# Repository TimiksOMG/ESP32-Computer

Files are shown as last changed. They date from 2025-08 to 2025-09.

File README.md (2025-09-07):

<h1>About</h1>
This is an open source computer with a custom language called TimCode and a DOS-like operating system called HamburgerOS<br>

It uses the <b>esp32-s3</b> chip with the <b>ILI9341</b> tft screen as a display.<br>
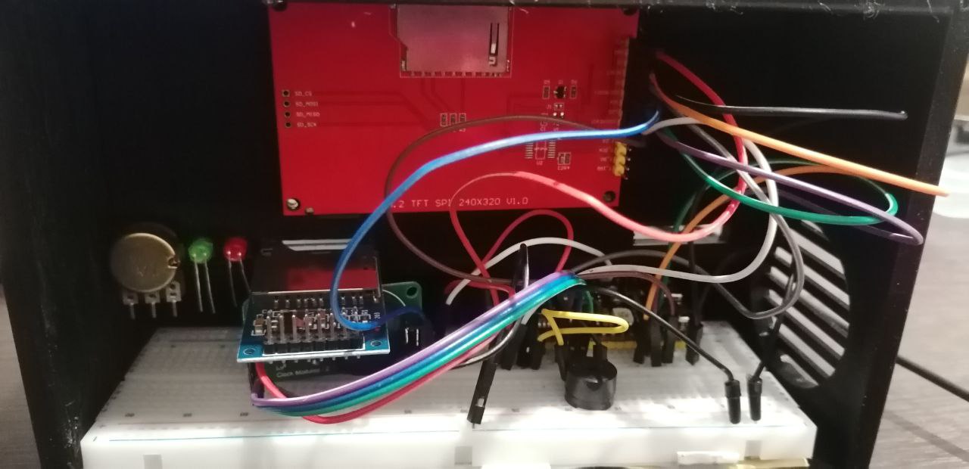
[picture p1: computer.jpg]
<br><br>

I made a custom programming language called <b>TimCode</b> for it so i can code the apps without compiling them.<br>
This also makes it easy to change the apps, as you don't have to change the firmware<br><br>

You can edit the project, or make a program in TimCode and i will make a video about it.<br>
Critique and questions appreciated. <br><br>

<h1>Price</h1>
<h6>I bought everything off aliexpress, so it's pretty cheap<br> Note: Prices are without shipping</h6>
<ul>
  <h5>Main parts</h5>
  <li><a href="https://aliexpress.ru/item/1005005046708221.html">ESP32 s3 - 345₽ / 4.29$</a></li>
  <li><a href="https://aliexpress.ru/item/1005004147439619.html">3.5in display - 471₽ / 5.86$</a></li>
  <li><a href="https://aliexpress.ru/item/1654409370.html">SD module - 36₽ / 0.45$</a></li>

  <h5>Keyboard</h5>
  <li><a href="https://aliexpress.ru/item/1005003115135192.html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">Buttons DIP4 H20MM 50 parts - 153₽ / 1,88$</a></li>
  <li><a href="https://aliexpress.ru/item/1005008763981613.html">One-sided breadboard 10x20cm - 82₽ / 1$</a></li>
  <li><a href="https://aliexpress.ru/item/1005005046708221.html">ESP32 s3 - 345₽ / 4.29$</a></li>
  <h6>You can use any controller for the keyboard</h6>
</ul><br><br>

<h1>Console commands</h1>
<h6>parameter(p) means optional.</h6>

<h2>Basic commands</h2

<h4>info - no parameters</h4>
Shows an ASCII art of a hamburger with info and time<br><br>

<h4>beep - tone(p), time(p)</h4>
Makes a square wave with provided parameters<br><br>

<h4>wait - time</h4>
Delays the system by a given amount of time (ms)<br><br>

<h4>mode - no parameters</h4>
Toggles beetwen Console and TimCode modes<br><br>

<h4>echo - ypos, string</h4>
Displays the text onscreen in the given y position (will be updated)<br><br>

<h4>clr - no parameters</h4>
Clears the screen and display the current mode (if out is enabled)<br><br>

<h4>noout - no parameters</h4>
Toggles beetwen out mode (true, false)<br><br>

<h4>goto - line</h4>
(used in TimCode) Sets the current line to provided<br><br>

<h4>timeset - second, minute, hour, day, month (single digit), year (two digits)</h4>
Sets the RTC module time to provided<br><br>

<h4>reset - no parameters</h4>
Resets the esp32<br><br><br>

<h2>Graphics commands</h2>

<h4>drawpoint - x, y, r, g, b, a</h4>
Draws a single point (pixel) onscreen<br><br>

<h4>drawline - x1, y1, x2, y2, r, g, b, a</h4>
Draws a line onscreen<br><br>

<h4>drawrect - x, y, w, h, r, g, b, a</h4>
Draws a rectangle with a given width and height<br><br>

<h4>fillrect - x, y, w, h, r, g, b, a</h4>
Draws a filled rectangle with a given width and height<br><br>

<h4>drawtri - x1, y1, x2, y2, x3, y3, r, g, b, a</h4>
Draws a triangle<br><br>

<h4>filltri - x1, y1, x2, y2, x3, y3, r, g, b, a</h4>
Draws a filled triangle<br><br>

<h4>drawcircle - x, y, rad, r,g,b,a</h4>
Draws a circle with a given radius<br><br>

<h4>fillcircle - x, y, rad, r,g,b,a</h4>
Draws a filled circle with a given radius<br><br>

<h2>SD commands</h2>

<h4>sdstart - no parameters</h4>
Starts the SD module<br><br>

<h4>sdlist - dir</h4>
Displays the directory contents<br><br>

<h4>sdmkdir - dir</h4>
Creates a directory<br><br>

<h4>sdrmdir - dir</h4>
Deletes a directory<br><br>

<h4>sdopen - dir</h4>
Opens a file and displays the contents in ASCII<br><br>

<h4>sdopen, sdappend - dir, content</h4>
Opens and writes to file. If file is not present, creates it. (basically the same)<br><br>

<h4>sdremove - dir</h4>
Deletes a file<br><br>

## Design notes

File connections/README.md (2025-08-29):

<h1>Physical connections</h1>

<h2>Display</h2>
<ul>
  <li>MISO-13</li>
  <li>MOSI-11</li>
  <li>SCK-12</li>
  <li>CS-10</li>
  <li>DC-2 (might change)</li>
  <li>RST-4</li>
</ul>
<h3>Warning</h3>
You must replace <b>User_Setup.h</b> and <b>Setup42_ILI9341_ESP32.h</b> in the tft_espi library folder with which are presented here<br>
<ul>
  <li>User_Setup.h is located in TFT_eSPI/</li>
  <li>Setup42_ILI9341_ESP32.h is located in TFT_eSPI/User_setups/</li>
</ul>

<h2>SD module (SPI, only for esp32 s3)</h2>
<ul>
  <li>CS-5</li>
  <li>SCLK-10</li>
  <li>MISO-8</li>
  <li>MOSI-3</li>
</ul>

<h2>DS1302 (rtc)</h2>
<ul>
  <li>CLK-15</li>
  <li>DAT-16</li>
  <li>RST-17</li>
</ul>

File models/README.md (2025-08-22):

<h2>About the models</h2>
These are the case models.
Files with .m3d must be opened with KOMPAS 3D.
If you can't, use the stl files

<h4>WARNING!</h4>
The models have some issues. Some holes are too small, and some are missing.
Printing takes about 15 hours (0.4mm nozzle), so print at your own risk. (don't worry, i will change that later)

<h2>Dimensions</h2>
(Note: these dimensions are for the provided models. You can change them as you want)<br><br>

<ul>
  <li>All the screws are 3mm</li>
  <li>The screen is 3.5inch (78mm by 55mm).</li>
  <li>Keyboard is 173mm by 65mm</li>
  <li>Speaker should be around 4.5mm in diameter</li>
  <li>Components that go in the back must not be longer than ~5cm</li>
</ul>

<h4>Components on the front are:</h4>
<ul>
  <li>Potentiometer, the stick is 7mm wide</li>
  <li>Two LEDs, each one is ~5mm wide</li>
  <li>SD card slot which is 29x3mm</li>
  <li>Two GPIO rows, 10 in each row.</li>
</ul>

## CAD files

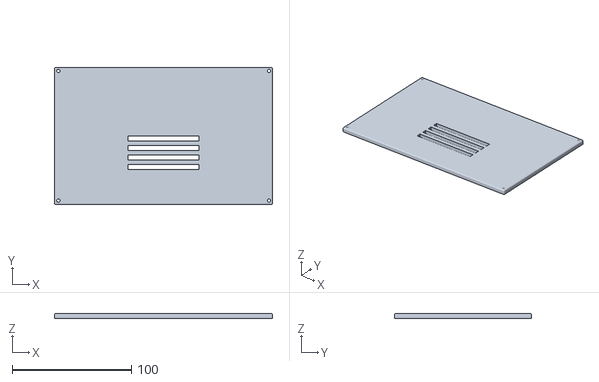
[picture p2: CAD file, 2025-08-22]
models/computer_cover.stl
183.0 x 115.0 x 4.00

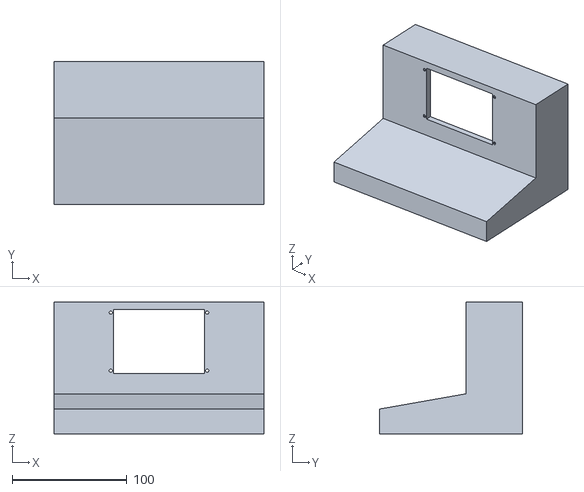
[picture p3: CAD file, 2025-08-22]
models/computer-case.stl
183.0 x 125.0 x 115.0

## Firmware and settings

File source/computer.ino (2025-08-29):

#include "console.hpp"

//rtc setup
#include <Ds1302.h>
const int RST_PIN = 17;  // Пин для управления
const int DAT_PIN = 16;  // Пин для передачи данных
const int CLK_PIN = 15;  // Пин для синхронизации тактов
Ds1302 srtc(RST_PIN, CLK_PIN, DAT_PIN);

void setup()
{
  //setup the serial port
  Serial.begin(115200);
  while (!Serial) {
    delay(10);
  }

  //initialize rtc
  srtc.init();
 
  //initialize rtc rime
  if (srtc.isHalted()) {
    Serial.println("RTC не настроен. Установка времени...");
 
    Ds1302::DateTime dt = {
      .year = 25,
      .month = 8,
      .day = 29,
      .hour = 20,
      .minute = 57,
      .second = 15,
    };
 
    //set
    srtc.setDateTime(&dt);
  }

  //start the console setup
  console::setup();
}

void loop()
{
  //console check
  console::read();

  /*
  //tried something with eeprom
  if(millis / 1000 % EEPROM.read(0) * 6000 == 0){
    EEPROM.begin(2);
    if(EEPROM.read(1) == 255){
      EEPROM.write(1, 0);
      EEPROM.write(0, EEPROM.read(0) + 1);
    }
    EEPROM.write(1, (uint8_t)millis / EEPROM.read(0) * (uint8_t)60000);
    EEPROM.commit();
    EEPROM.end();
  }
  */
}

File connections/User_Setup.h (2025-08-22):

/* 
  Rui Santos & Sara Santos - Random Nerd Tutorials

  Install the "TFT_eSPI" library by Bodmer to interface with the TFT Display - https://github.com/Bodmer/TFT_eSPI
  *** IMPORTANT: User_Setup.h available on the internet will probably NOT work with the examples available at Random Nerd Tutorials ***
  *** YOU MUST USE THIS User_Setup.h FILE, CHECK FOR THE LATEST VERSION IN THE LINK BELOW IN ORDER TO USE THE EXAMPLES FROM RANDOM NERD TUTORIALS ***
  https://RandomNerdTutorials.com/cyd/
  https://RandomNerdTutorials.com/esp32-tft/
  FULL INSTRUCTIONS AVAILABLE ON HOW CONFIGURE THE LIBRARY: https://RandomNerdTutorials.com/cyd/ or https://RandomNerdTutorials.com/esp32-tft/
*/

//                            USER DEFINED SETTINGS
//   Set driver type, fonts to be loaded, pins used and SPI control method etc
//
//   See the User_Setup_Select.h file if you wish to be able to define multiple
//   setups and then easily select which setup file is used by the compiler.
//
//   If this file is edited correctly then all the library example sketches should
//   run without the need to make any more changes for a particular hardware setup!
//   Note that some sketches are designed for a particular TFT pixel width/height

// User defined information reported by "Read_User_Setup" test & diagnostics example
#define USER_SETUP_INFO "User_Setup"

// Define to disable all #warnings in library (can be put in User_Setup_Select.h)
//#define DISABLE_ALL_LIBRARY_WARNINGS

// ##################################################################################
//
// Section 1. Call up the right driver file and any options for it
//
// ##################################################################################

// Define STM32 to invoke optimised processor support (only for STM32)
//#define STM32

// Defining the STM32 board allows the library to optimise the performance
// for UNO compatible "MCUfriend" style shields
//#define NUCLEO_64_TFT
//#define NUCLEO_144_TFT

// STM32 8 bit parallel only:
// If STN32 Port A or B pins 0-7 are used for 8 bit parallel data bus bits 0-7
// then this will improve rendering performance by a factor of ~8x
//#define STM_PORTA_DATA_BUS
//#define STM_PORTB_DATA_BUS

// Tell the library to use parallel mode (otherwise SPI is assumed)
//#define TFT_PARALLEL_8_BIT
//#defined TFT_PARALLEL_16_BIT // **** 16 bit parallel ONLY for RP2040 processor ****

// Display type -  only define if RPi display
//#define RPI_DISPLAY_TYPE // 20MHz maximum SPI

// Only define one driver, the other ones must be commented out
#define ILI9341_DRIVER       // Generic driver for common displays
//#define ILI9341_2_DRIVER     // Alternative ILI9341 driver, see https://github.com/Bodmer/TFT_eSPI/issues/1172
//#define ST7735_DRIVER      // Define additional parameters below for this display
//#define ILI9163_DRIVER     // Define additional parameters below for this display
//#define S6D02A1_DRIVER
//#define RPI_ILI9486_DRIVER // 20MHz maximum SPI
//#define HX8357D_DRIVER
//#define ILI9481_DRIVER
//#define ILI9486_DRIVER
//#define ILI9488_DRIVER     // WARNING: Do not connect ILI9488 display SDO to MISO if other devices share the SPI bus (TFT SDO does NOT tristate when CS is high)
//#define ST7789_DRIVER      // Full configuration option, define additional parameters below for this display
//#define ST7789_2_DRIVER    // Minimal configuration option, define additional parameters below for this display
//#define R61581_DRIVER
//#define RM68140_DRIVER
//#define ST7796_DRIVER
//#define SSD1351_DRIVER
//#define SSD1963_480_DRIVER
//#define SSD1963_800_DRIVER
//#define SSD1963_800ALT_DRIVER
//#define ILI9225_DRIVER
//#define GC9A01_DRIVER

// Some displays support SPI reads via the MISO pin, other displays have a single
// bi-directional SDA pin and the library will try to read this via the MOSI line.
// To use the SDA line for reading data from the TFT uncomment the following line:

// #define TFT_SDA_READ      // This option is for ESP32 ONLY, tested with ST7789 and GC9A01 display only

// For ST7735, ST7789 and ILI9341 ONLY, define the colour order IF the blue and red are swapped on your display
// Try ONE option at a time to find the correct colour order for your display

//  #define TFT_RGB_ORDER TFT_RGB  // Colour order Red-Green-Blue
//  #define TFT_RGB_ORDER TFT_BGR  // Colour order Blue-Green-Red

// For M5Stack ESP32 module with integrated ILI9341 display ONLY, remove // in line below

// #define M5STACK

// For ST7789, ST7735, ILI9163 and GC9A01 ONLY, define the pixel width and height in portrait orientation
// #define TFT_WIDTH  80
// #define TFT_WIDTH  128
// #define TFT_WIDTH  172 // ST7789 172 x 320
#define TFT_WIDTH  240 // ST7789 240 x 240 and 240 x 320
// #define TFT_HEIGHT 160
// #define TFT_HEIGHT 128
// #define TFT_HEIGHT 240 // ST7789 240 x 240
#define TFT_HEIGHT 320 // ST7789 240 x 320
// #define TFT_HEIGHT 240 // GC9A01 240 x 240

// For ST7735 ONLY, define the type of display, originally this was based on the
// colour of the tab on the screen protector film but this is not always true, so try
// out the different options below if the screen does not display graphics correctly,
// e.g. colours wrong, mirror images, or stray pixels at the edges.
// Comment out ALL BUT ONE of these options for a ST7735 display driver, save this
// this User_Setup file, then rebuild and upload the sketch to the board again:

// #define ST7735_INITB
// #define ST7735_GREENTAB
// #define ST7735_GREENTAB2
// #define ST7735_GREENTAB3
// #define ST7735_GREENTAB128    // For 128 x 128 display
// #define ST7735_GREENTAB160x80 // For 160 x 80 display (BGR, inverted, 26 offset)
// #define ST7735_ROBOTLCD       // For some RobotLCD arduino shields (128x160, BGR, https://docs.arduino.cc/retired/getting-started-guides/TFT)
// #define ST7735_REDTAB
// #define ST7735_BLACKTAB
// #define ST7735_REDTAB160x80   // For 160 x 80 display with 24 pixel offset

// If colours are inverted (white shows as black) then uncomment one of the next
// 2 lines try both options, one of the options should correct the inversion.

// #define TFT_INVERSION_ON
// #define TFT_INVERSION_OFF


// ##################################################################################
//
// Section 2. Define the pins that are used to interface with the display here
//
// ##################################################################################

// If a backlight control signal is available then define the TFT_BL pin in Section 2
// below. The backlight will be turned ON when tft.begin() is called, but the library
// needs to know if the LEDs are ON with the pin HIGH or LOW. If the LEDs are to be
// driven with a PWM signal or turned OFF/ON then this must be handled by the user
// sketch. e.g. with digitalWrite(TFT_BL, LOW);

//#define TFT_BL   21            // LED back-light control pin
//#define TFT_BACKLIGHT_ON HIGH  // Level to turn ON back-light (HIGH or LOW)
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
